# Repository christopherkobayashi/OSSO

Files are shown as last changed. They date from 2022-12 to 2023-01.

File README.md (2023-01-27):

# Osso

Osso is a BeagleBone (White/Black/Green) I/O expansion cape.

The Osso was designed by Franco (nextime) Lanza <franco@nexlab.it>

## Output

The Osso has 8 relays rated at 275VAC@10A.

## Input
Osso has 8 digital inputs.  They can be switched between opto-isolated and non-opto-isolated; the instructions are [here](INPUTS.md)

## Power

The expansion cape is powered by a 12VDC connector (9 to 24VDC supported).  The Osso will supply power to the BeagleBone via the expansion pins.

## Software

A test Debian GNU/Linux install is available.  Installation instructions are [here](TEST.md)

## Miscellaneous

The size of the cape is a standard format for 9 units DIN mount boxes.

## Pictures

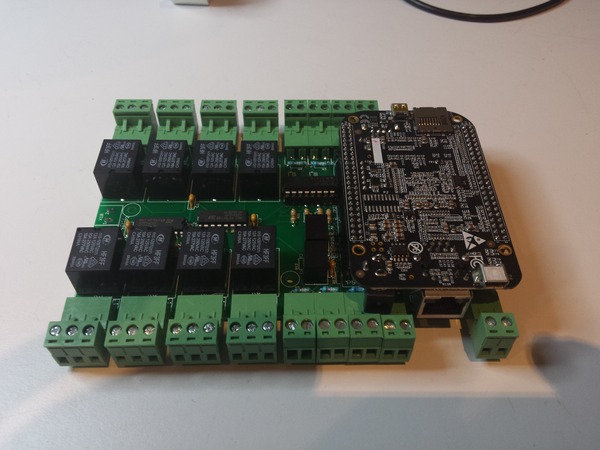
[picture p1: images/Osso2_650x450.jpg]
Osso board

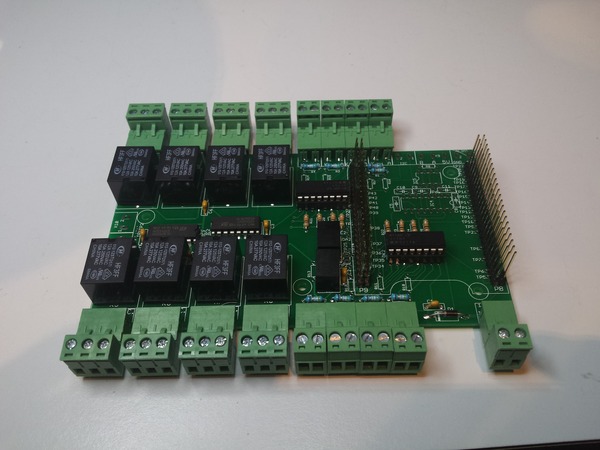
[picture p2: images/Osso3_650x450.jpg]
Osso board


Pin diagram (green dot pins are optional, other required):

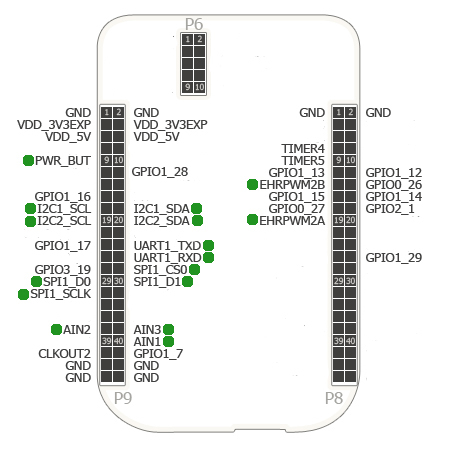
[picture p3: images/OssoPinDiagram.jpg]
Osso Pin Diagram


## Miscellaneous

For more information, please visit https://www.nexlab.net/

Do you like our cape? Donations in Bitcoin is accepted at 1ABepVhyYuZNxiMQe8atPi4tRJZKkpRDqb (CK note: verify this address with nextime before sending any Bitcoin!)

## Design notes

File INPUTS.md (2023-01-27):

# Osso inputs: opto or non-opto insulated digital inputs.

Osso come with the ability to change digital inputs to optoinsulated or non optoinsulated.

Which one you need to use depend on what you really need:

If you want to have a simple "open close" circuit, with a clean contact like a simple push button, and you don't have interference issues or very long ( > 50 meters ) wiring for inputs, non-opto insulated it's the way to go.

If you need to push current to the inputs, opto-insulated is your right choice, so, you can put from 2 to 24V DC voltage on the digital inputs.

Switch from one to another on Osso is easy: you just need to swap some IC, and in the last case to solder 8 resistors.

Inputs on Osso are organized in groups of 4: from 1 to 4 and from 5 to 8. Different groups can be used in different modes.

With Osso we provide also a couple of ICs, so, you don't need any other spare component.

We provide: 

* 2x DIP16 TLP521-4x opto-decoupler 
* 2x 4116-R LF resistors array

By default, if nor otherwise requested, we mount on Osso the array resistors for non-opto isolated inputs.

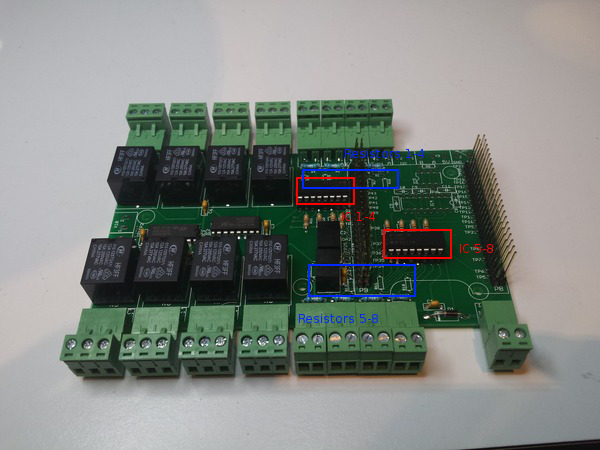
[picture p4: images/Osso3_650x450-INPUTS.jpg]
Osso board


## Opto-insulated configuration
Uses TLP521-4x ICs in the two dip16 sockets as on the image, no resistors are needed. You will need to put 2 to 24 Volts on the input to change input status ( resistors on inputs are for max 250mW! )

## Non-opto insulated configuration
Uses 4116R-LF ICs in the two dip16 sockets as on the image, no resistors are needed. It will change input status on short.

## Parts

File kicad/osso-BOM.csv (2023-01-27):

Source: | /home/wileyc/src/OSSO/kicad/osso.kicad_sch
Date: | Fri 27 Jan 2023 08:09:53 PM JST
Tool: | Eeschema (6.0.11)
Generator: | /usr/share/kicad/plugins/bom_csv_grouped_by_value_with_fp.py
Component Count: | 150
Ref | Qnty | Value | Cmp name | Footprint | Description | Vendor
ALIM0, ALIM1, | 2 | Alim | MORSETTO_2 | osso:W237-102
C1, C2, C3, C4, C5, C6, C7, C8, C9, C10, C11, | 11 | C5/2.5 | C5{slash}2.5 | osso:C5B2.5
D1, | 1 | DIODE | DIODE | osso:DO15-12
H1, H2, H3, H4, H5, | 5 | HOLE3.0 | HOLE3.0 | osso:3,0
I2C0, | 1 | I2C | MORSETTO_2 | osso:W237-102
IC1, IC6, | 2 | REGOLATORE_TENSIONESWITCHING | REGOLATORE_TENSIONESWITCHING | osso:MT6-3
IC2, IC3, | 2 | ULN2003AN | ULN2003AN | osso:DIL16
IC4, | 1 | MAX202CPE | MAX202CPE | osso:DIL16
IC5, | 1 | MAX481CPA | MAX481CPA | osso:DIL08
IN1, | 1 | IN1 | MORSETTO_2 | osso:W237-102
IN2, | 1 | IN2 | MORSETTO_2 | osso:W237-102
IN3, | 1 | IN3 | MORSETTO_2 | osso:W237-102
IN4, | 1 | IN4 | MORSETTO_2 | osso:W237-102
IN5, | 1 | IN5 | MORSETTO_2 | osso:W237-102
IN6, | 1 | IN6 | MORSETTO_2 | osso:W237-102
IN7, | 1 | IN7 | MORSETTO_2 | osso:W237-102
IN8, | 1 | IN8 | MORSETTO_2 | osso:W237-102
J1, | 1 | RTC_MICROROBOT_ALGOZINO-PTH | RTC_MICROROBOT_ALGOZINO-PTH | osso:RTC_MICROBOT_ALGOZINO
JP1, | 1 | JUMPER_2 | JUMPER_2 | osso:JP1
K1, K2, K3, K4, K5, K6, K7, K8, | 8 | RELAY | RELAY | osso:G5LE
OK1, OK2, | 2 | OPTOISOLATORE_ILQ620 | OPTOISOLATORE_ILQ620 | osso:DIL16
PCB1, | 1 | BORDO_UNIXMEDIA150X83,5 | BORDO_UNIXMEDIA150X83,5 | osso:BORD_UNIXMEDIA
R1, R2, R3, R4, R5, R6, R7, R8, | 8 | 49 | RESISTOR0204{slash}7 | osso:0204_7
R9, R13, R15, R23, | 4 | RESISTOR0204/7 | RESISTOR0204{slash}7 | osso:0204_7
R10, R11, R12, R14, R16, R17, R18, R19, R20, R21, R22, R24, R25, | 13 | 10k | RESISTOR0204{slash}7 | osso:0204_7
SCL2, | 1 | TPPAD1-13 | TPPAD1-13 | osso:TEST_POINT
SDA2, | 1 | TP1 | TPPAD1-13 | osso:TEST_POINT
SS1, | 1 | CE-MARK | CE-MARK | osso:CE-MARK-0.2
SS2, | 1 | PB-MARK | PB-MARK | osso:PB-MARK-0.2
TP1, TP2, TP3, TP4, TP5, TP6, TP7, TP8, TP9, TP10, TP11, TP12, TP13, TP14, TP15, TP16, TP17, TP18, TP19, TP20, TP21, TP22, TP23, TP24, TP25, TP26, TP27, TP28, TP29, TP30, TP31, TP32, TP33, TP34, TP35, TP36, TP37, TP38, TP39, TP40, TP41, TP42, TP43, TP44, TP45, TP46, TP47, TP48, TP49, TP50, TP51, TP52, TP53, TP54, TP55, TP56, TP57, TP58, TP59, TP60, TP61, TP62, | 62 | TPPAD1-13 | TPPAD1-13 | osso:TEST_POINT
U$1, | 1 | BEAGLEBONE_OUTLINE | BEAGLEBONE_OUTLINE | osso:BEAGLEBONE_SHIELD
X1, | 1 | X1 | MORSETTO_3 | osso:W237-103
X2, | 1 | X2 | MORSETTO_3 | osso:W237-103
X3, | 1 | X3 | MORSETTO_3 | osso:W237-103
X4, | 1 | X4 | MORSETTO_3 | osso:W237-103
X5, | 1 | X5 | MORSETTO_3 | osso:W237-103
X6, | 1 | X6 | MORSETTO_3 | osso:W237-103
X7, | 1 | X7 | MORSETTO_3 | osso:W237-103
X8, | 1 | X8 | MORSETTO_3 | osso:W237-103
X9, | 1 | MORSETTO_3 | MORSETTO_3 | osso:W237-103
X10, X11, | 2 | MORSETTO_2 | MORSETTO_2 | osso:W237-102

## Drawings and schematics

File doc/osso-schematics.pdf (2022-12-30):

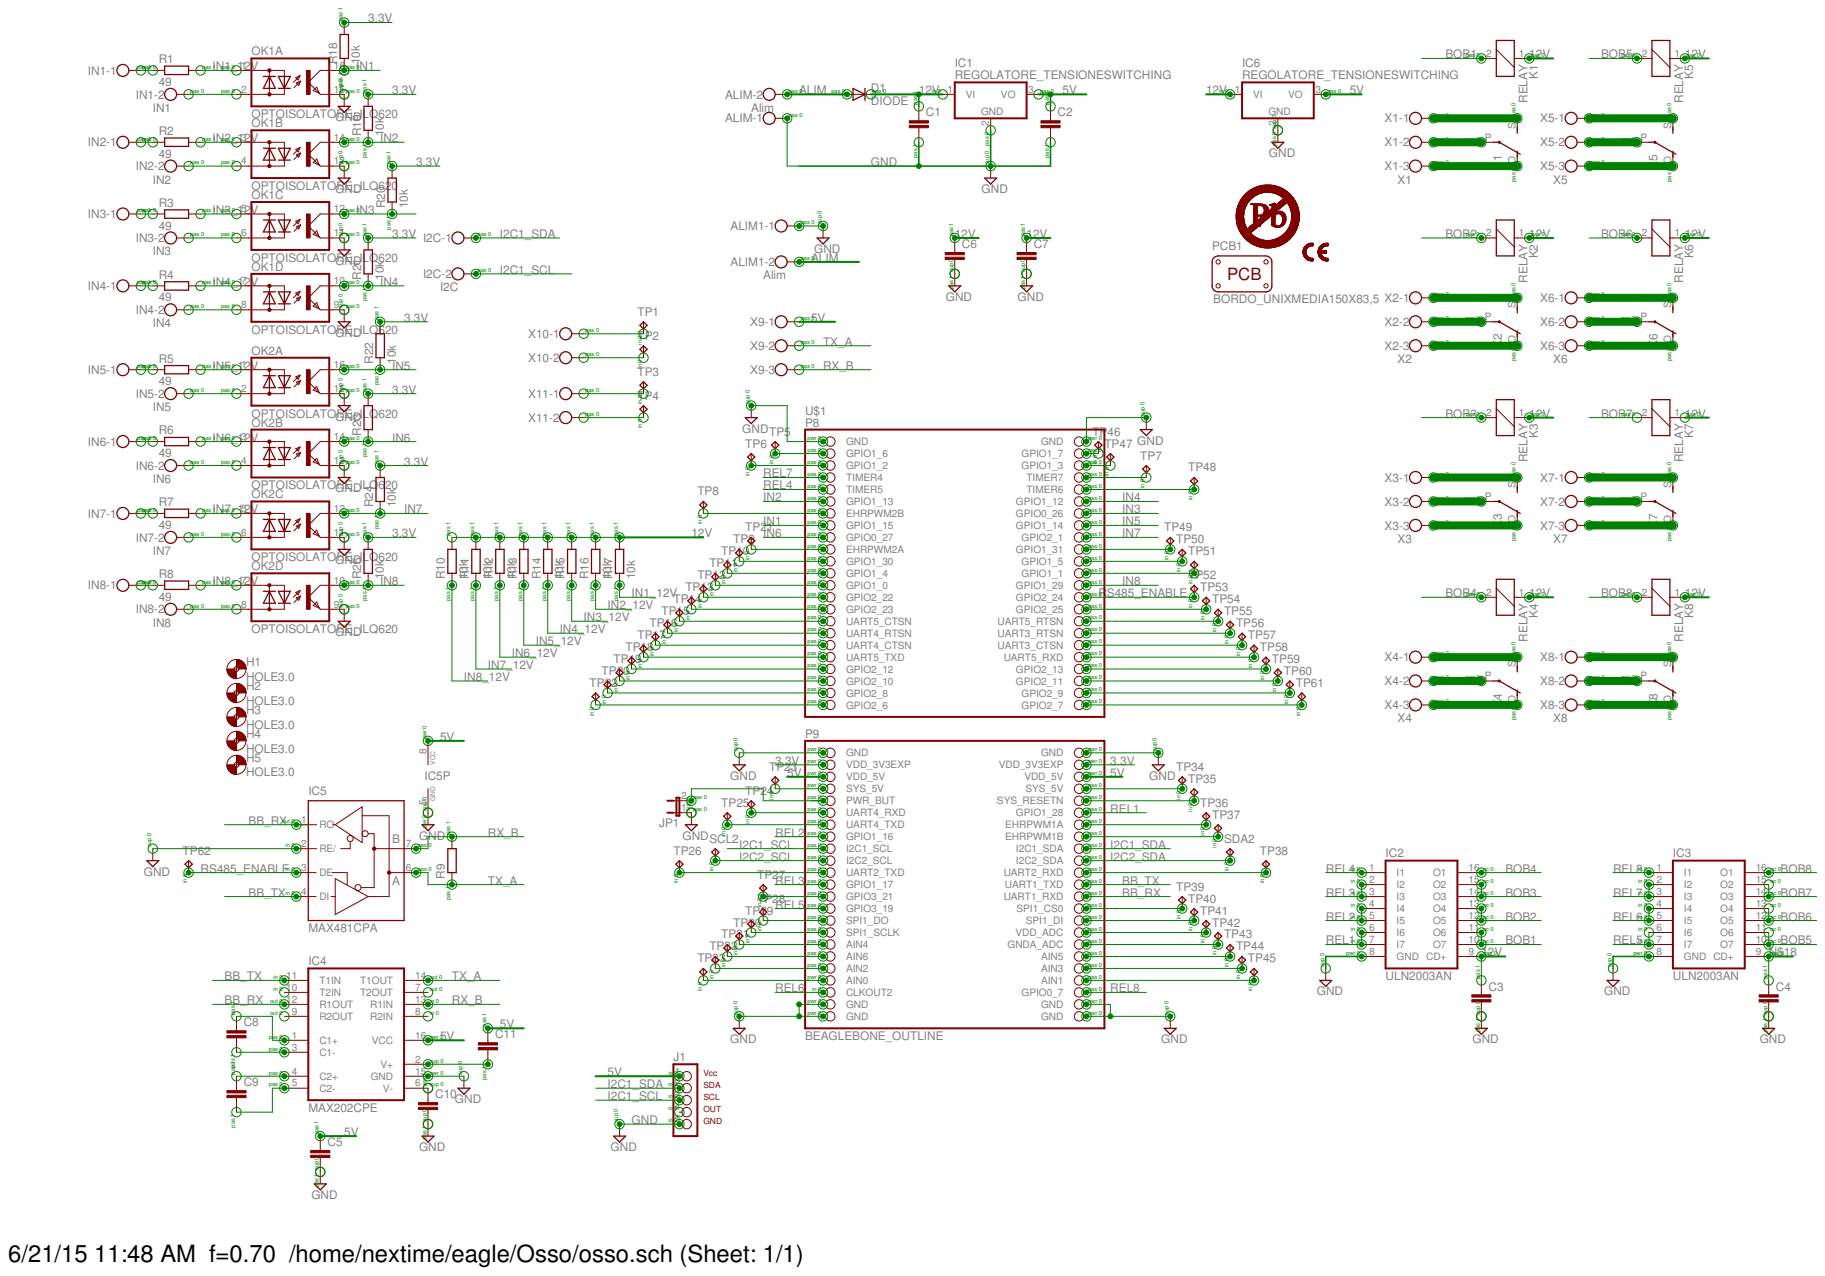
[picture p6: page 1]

RELAY RELAY

sup 0 sup 0 sup 0 sup 0
GND GND GND GND

pas 1 pas 1

6/21/15 11:48 AM f=0.70 /home/nextime/eagle/Osso/osso.sch (Sheet: 1/1)

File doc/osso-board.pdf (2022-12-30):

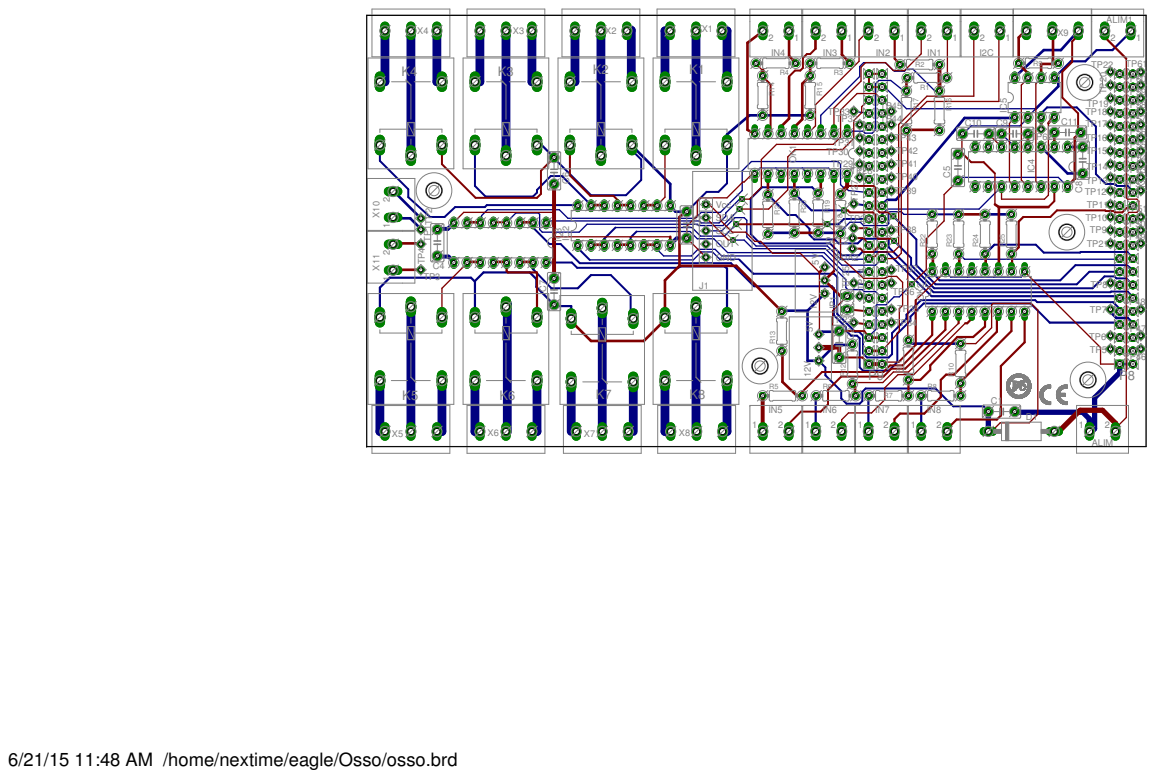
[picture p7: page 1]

ALIM1
TP49 TP50 TP51 TP52 TP53 TP54 TP55 TP56 TP57 TP58 TP59 TP60 TP61

6/21/15 11:48 AM /home/nextime/eagle/Osso/osso.brd

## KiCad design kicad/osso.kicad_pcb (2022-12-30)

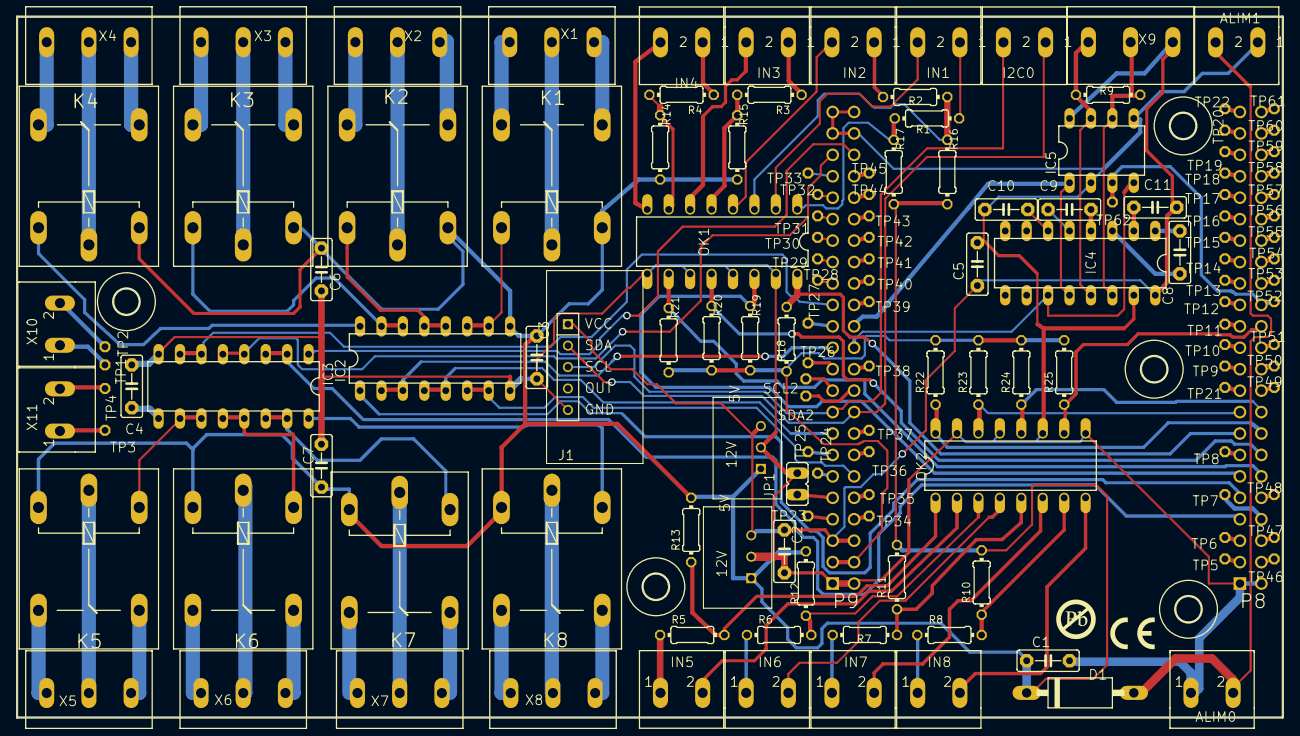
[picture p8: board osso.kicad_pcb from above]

Board: 4 copper layers, 150.0 x 83.0 mm, 150 parts (1 on the bottom side), 154 nets.

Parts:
ALIM0, ALIM1: Alim; W237-102
C1, C2, C3, C4, C5, C6, C7, C8, C9, C10, C11: C5B2.5
D1: DIODE; DO15-12
H1, H2, H3, H4, H5: HOLE3.0; 3,0
I2C0: I2C; W237-102
IC1, IC6: REGOLATORE_TENSIONESWITCHING; MT6-3
IC2, IC3: ULN2003AN; DIL16
IC4: MAX202CPE; DIL16
IC5: MAX481CPA; DIL08
IN1: IN1; W237-102
IN2: IN2; W237-102
IN3: IN3; W237-102
IN4: IN4; W237-102
IN5: IN5; W237-102
IN6: IN6; W237-102
IN7: IN7; W237-102
IN8: IN8; W237-102
J1: RTC_MICROROBOT_ALGOZINO-PTH; RTC_MICROBOT_ALGOZINO
JP1: JP1
K1, K2, K3, K4, K5, K6, K7, K8: RELAY; G5LE
OK1, OK2: OPTOISOLATORE_ILQ620; DIL16
PCB1: BORDO_UNIXMEDIA150X83,5; BORD_UNIXMEDIA
R1, R2, R3, R4, R5, R6, R7, R8: 49; 0204_7
R9, R13, R15, R23: 0204_7
R10, R11, R12, R14, R16, R17, R18, R19, R20, R21, R22, R24, R25: 10k; 0204_7
SCL2: TPPAD1-13; TEST_POINT
SDA2: TP1; TEST_POINT
SS1: CE-MARK; CE-MARK-0.2
SS2: PB-MARK; PB-MARK-0.2
TP1, TP2, TP3, TP4, TP5, TP6, TP7, TP8, TP9, TP10, TP11, TP12, TP13, TP14, TP15, TP16, TP17, TP18, TP19, TP20, TP21, TP22, TP23, TP24, TP25, TP26, TP27, TP28, TP29, TP30, TP31, TP32, TP33, TP34, TP35, TP36, TP37, TP38, TP39, TP40, TP41, TP42, TP43, TP44, TP45, TP46, TP47, TP48, TP49, TP50, TP51, TP52, TP53, TP54, TP55, TP56, TP57, TP58, TP59, TP60, TP61, TP62: TPPAD1-13; TEST_POINT
U$1: BEAGLEBONE_OUTLINE; BEAGLEBONE_SHIELD
X1: X1; W237-103
X2: X2; W237-103
X3: X3; W237-103
X4: X4; W237-103
X5: X5; W237-103
X6: X6; W237-103
X7: X7; W237-103
X8: X8; W237-103
X9: W237-103
X10, X11: W237-102

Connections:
3.3V: R18.2, R19.2, R20.2, R21.2, R22.2, R23.2, R24.2, R25.2, U$1.49, U$1.50
5V: C2.1, C5.1, C11.1, IC1.3, IC4.16, IC5.8, IC6.3, J1.1, U$1.51, U$1.52, X9.1
12V: C1.1, C3.1, C6.1, C7.1, D1.C, IC1.1, IC2.9, IC6.1, K1.1, K2.1, K3.1, K4.1, K5.1, K6.1, K7.1, K8.1, R10.2, R11.2, R12.2, R13.2, R14.2, R15.2, R16.2, R17.2
ALIM: ALIM0.2, ALIM1.2, D1.A
BB_RX: IC4.12, IC5.1, U$1.72
BB_TX: IC4.11, IC5.4, U$1.70
BOB1: IC2.10, IC2.11, K1.2
BOB2: IC2.12, IC2.13, K2.2
BOB3: IC2.14, IC2.15, K3.2
BOB4: IC2.16, K4.2
BOB5: IC3.10, IC3.11, K5.2
BOB6: IC3.12, IC3.13, K6.2
BOB7: IC3.14, IC3.15, K7.2
BOB8: IC3.16, K8.2
GND: ALIM0.1, ALIM1.1, C1.2, C2.2, C3.2, C4.2, C5.2, C6.2, C7.2, C10.2, IC1.2, IC2.8, IC3.8, IC4.15, IC5.2, IC5.5, IC6.2, J1.5, JP1.1, OK1.9, OK1.11, OK1.13, OK1.15, OK2.9, OK2.11, OK2.13, OK2.15, U$1.1, U$1.2, U$1.47, U$1.48, U$1.89, U$1.90, U$1.91, U$1.92
I2C1_SCL: I2C0.2, J1.3, U$1.63
I2C1_SDA: I2C0.1, J1.2, U$1.64
I2C2_SCL: SCL2.TP, U$1.65
I2C2_SDA: SDA2.TP, U$1.66
IN1: OK1.16, R18.1, U$1.15
IN1_12V: OK1.1, R1.2, R17.1
IN2: OK1.14, R19.1, U$1.11
IN2_12V: OK1.3, R2.2, R16.1
IN3: OK1.12, R20.1, U$1.14
IN3_12V: OK1.5, R3.2, R15.1
IN4: OK1.10, R21.1, U$1.12
IN4_12V: OK1.7, R4.2, R14.1
IN5: OK2.16, R22.1, U$1.16
IN5_12V: OK2.1, R5.2, R13.1
IN6: OK2.14, R23.1, U$1.17
IN6_12V: OK2.3, R6.2, R12.1
IN7: OK2.12, R24.1, U$1.18
IN7_12V: OK2.5, R7.2, R11.1
IN8: OK2.10, R25.1, U$1.26
IN8_12V: OK2.7, R8.2, R10.1
unnamed: IN1.1, R1.1
unnamed: TP1.TP, X10.1
unnamed: K5.S, X5.1
unnamed: K5.P, X5.2
unnamed: K5.O, X5.3
unnamed: K6.S, X6.1
unnamed: K6.P, X6.2
unnamed: K6.O, X6.3
unnamed: K3.S, X3.1
unnamed: K3.P, X3.2
unnamed: K3.O, X3.3
unnamed: C4.1, IC3.9
unnamed: K7.S, X7.1
unnamed: K7.P, X7.2
unnamed: K4.S, X4.1
unnamed: K4.P, X4.2
unnamed: K4.O, X4.3
unnamed: K8.S, X8.1
unnamed: K8.P, X8.2
unnamed: K8.O, X8.3
unnamed: IN2.1, R2.1
unnamed: TP2.TP, X10.2
unnamed: IN3.1, R3.1
unnamed: TP3.TP, X11.1
unnamed: IN4.1, R4.1
unnamed: TP4.TP, X11.2
unnamed: IN5.1, R5.1
unnamed: TP7.TP, U$1.8
unnamed: IN6.1, R6.1
unnamed: TP22.TP, U$1.45
unnamed: IN7.1, R7.1
unnamed: TP20.TP, U$1.43
unnamed: IN8.1, R8.1
unnamed: TP19.TP, U$1.41
unnamed: IN8.2, OK2.8
unnamed: IN7.2, OK2.6
unnamed: IN6.2, OK2.4
unnamed: IN5.2, OK2.2
unnamed: IN1.2, OK1.2
unnamed: IN2.2, OK1.4
unnamed: IN3.2, OK1.6
unnamed: IN4.2, OK1.8
unnamed: JP1.2, U$1.55
unnamed: TP18.TP, U$1.39
unnamed: TP17.TP, U$1.37
unnamed: TP16.TP, U$1.35
unnamed: TP15.TP, U$1.33
unnamed: TP14.TP, U$1.31
unnamed: TP13.TP, U$1.29
unnamed: TP12.TP, U$1.27
unnamed: TP11.TP, U$1.25
unnamed: TP10.TP, U$1.23
unnamed: TP9.TP, U$1.21
unnamed: TP21.TP, U$1.19
unnamed: TP5.TP, U$1.3
unnamed: TP6.TP, U$1.5
unnamed: K7.O, X7.3
unnamed: TP8.TP, U$1.13
unnamed: TP33.TP, U$1.85
unnamed: TP32.TP, U$1.83
unnamed: TP31.TP, U$1.81
unnamed: TP30.TP, U$1.79
unnamed: TP29.TP, U$1.77
unnamed: TP28.TP, U$1.75
unnamed: TP27.TP, U$1.71
unnamed: TP26.TP, U$1.67
unnamed: TP25.TP, U$1.59
unnamed: TP24.TP, U$1.57
unnamed: TP23.TP, U$1.53
unnamed: TP34.TP, U$1.54
unnamed: TP35.TP, U$1.56
unnamed: TP36.TP, U$1.60
unnamed: TP37.TP, U$1.62
unnamed: TP38.TP, U$1.68
unnamed: TP39.TP, U$1.74
unnamed: TP40.TP, U$1.76
unnamed: TP41.TP, U$1.78
unnamed: TP42.TP, U$1.80
unnamed: TP43.TP, U$1.82
unnamed: TP44.TP, U$1.84
unnamed: TP45.TP, U$1.86
unnamed: TP61.TP, U$1.46
unnamed: TP60.TP, U$1.44
unnamed: TP59.TP, U$1.42
unnamed: TP58.TP, U$1.40
unnamed: TP57.TP, U$1.38
unnamed: TP56.TP, U$1.36
unnamed: TP55.TP, U$1.34
unnamed: TP54.TP, U$1.32
unnamed: TP53.TP, U$1.30
unnamed: TP51.TP, U$1.24
unnamed: TP50.TP, U$1.22
unnamed: TP49.TP, U$1.20
unnamed: TP48.TP, U$1.10
unnamed: TP47.TP, U$1.6
unnamed: TP46.TP, U$1.4
unnamed: C8.1, IC4.1
unnamed: C8.2, IC4.3
unnamed: C9.1, IC4.4
unnamed: C9.2, IC4.5
R1_C: K1.P, X1.2
R1_NA: K1.S, X1.1
R1_NC: K1.O, X1.3
R2_C: K2.P, X2.2
R2_NA: K2.S, X2.1
R2_NC: K2.O, X2.3
REL1: IC2.6, IC2.7, U$1.58
REL2: IC2.4, IC2.5, U$1.61
REL3: IC2.2, IC2.3, U$1.69
REL4: IC2.1, U$1.9
REL5: IC3.6, IC3.7, U$1.73
REL6: IC3.4, IC3.5, U$1.87
REL7: IC3.2, IC3.3, U$1.7
REL8: IC3.1, U$1.88
RS485_ENABLE: IC5.3, TP52.TP, TP62.TP, U$1.28
RX_B: IC4.13, IC5.7, R9.2, X9.3
TX_A: IC4.14, IC5.6, R9.1, X9.2
V+: C11.2, IC4.2
V-: C10.1, IC4.6

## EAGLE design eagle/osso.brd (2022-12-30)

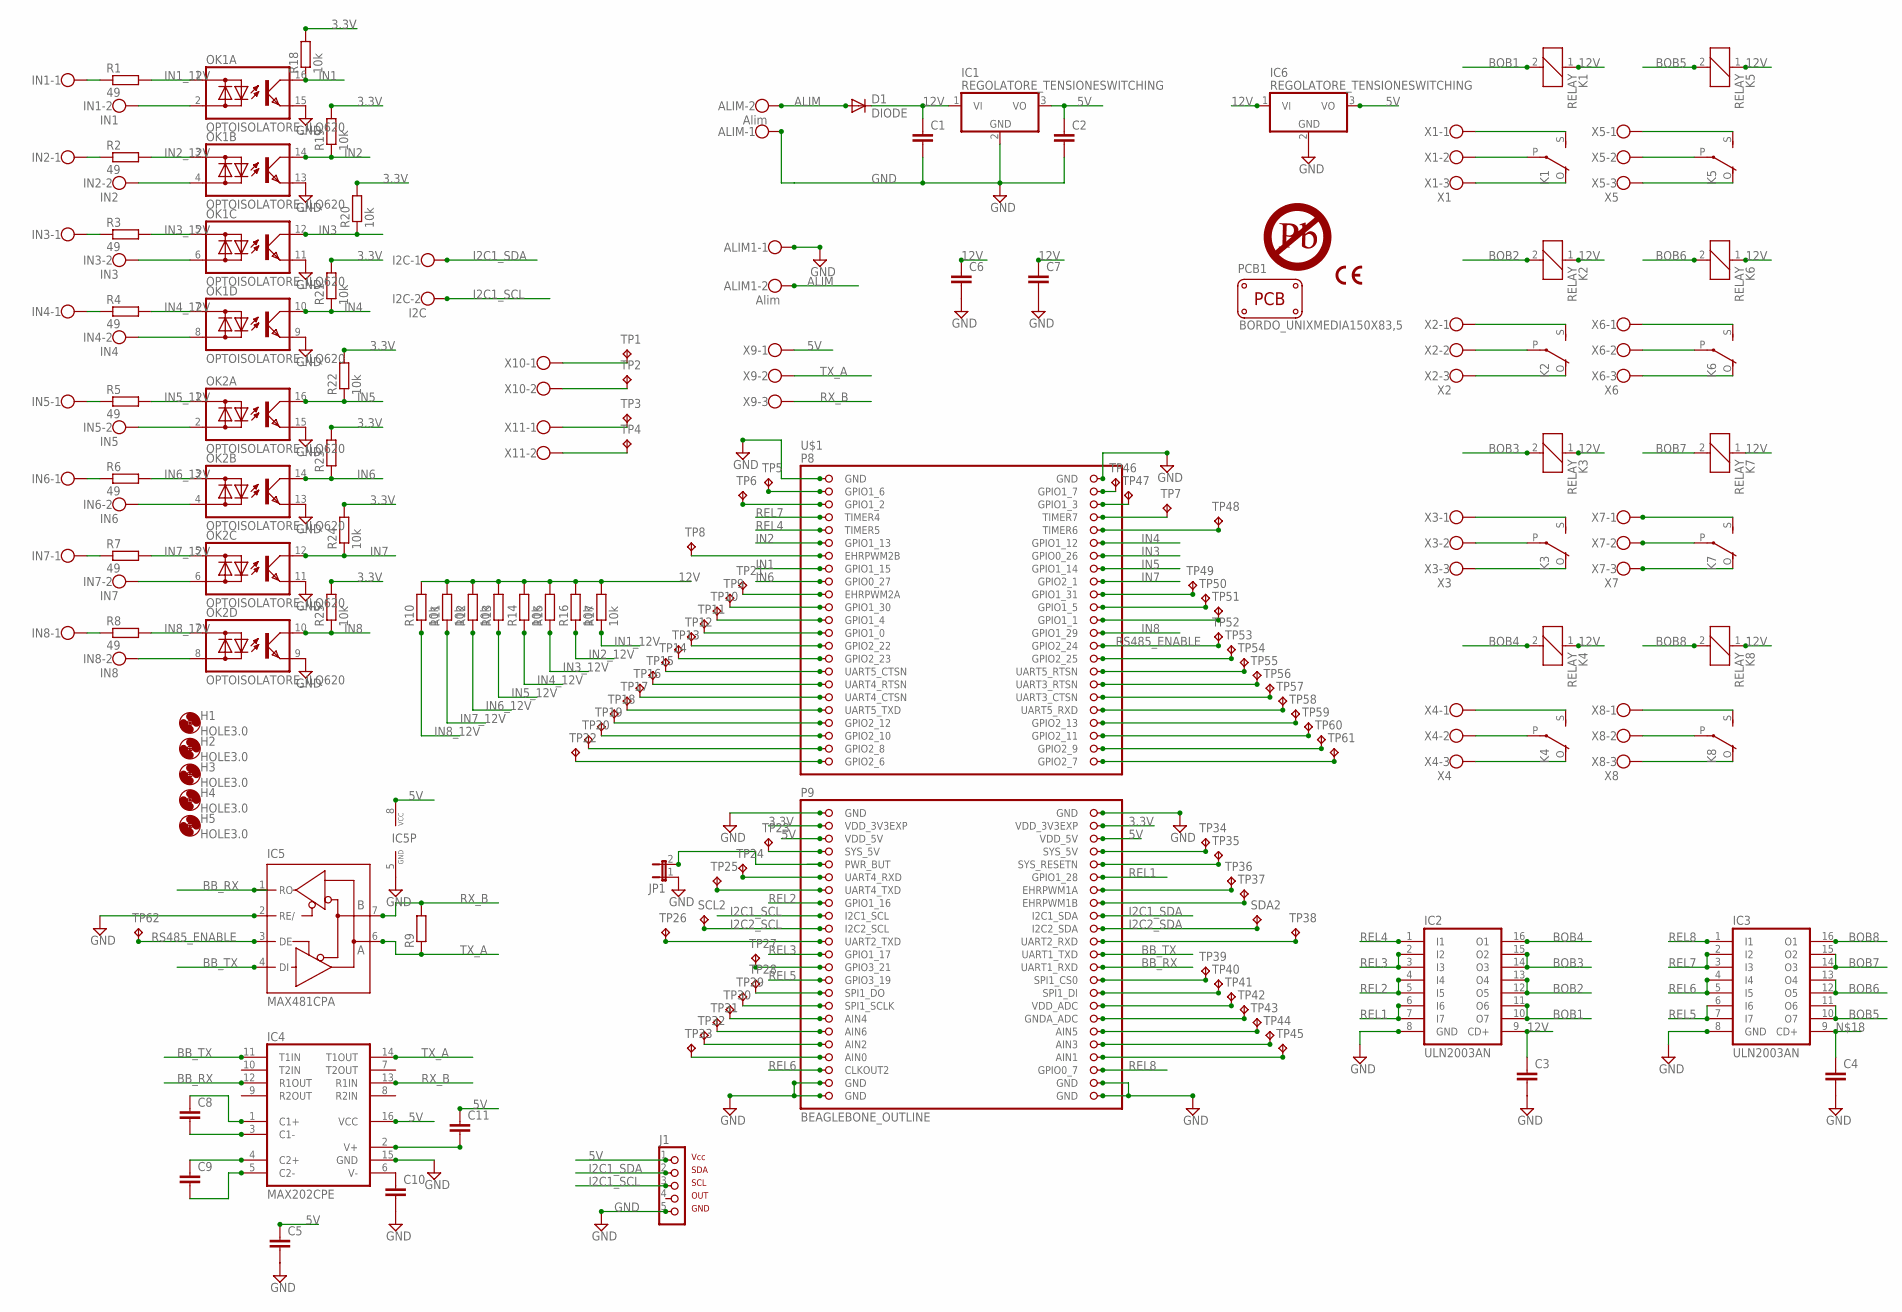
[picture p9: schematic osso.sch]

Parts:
ALIM: Alim; W237-102
ALIM1: Alim; W237-102; MPN 237-102
C1, C2, C3, C4, C5, C6, C7, C8, C9, C10, C11: C5/2.5; C5B2.5
D1: DIODE; DO15-12
H1, H2, H3, H4, H5: HOLE3.0; 3,0
I2C: I2C; W237-102; MPN 237-102
IC1, IC6: REGOLATORE_TENSIONESWITCHING; MT6-3
IC2, IC3: ULN2003AN; DIL16
IC4: MAX202CPE; DIL16
IC5: MAX481CPA; DIL08
IN1: IN1; W237-102
IN2: IN2; W237-102
IN3: IN3; W237-102
IN4: IN4; W237-102
IN5: IN5; W237-102
IN6: IN6; W237-102
IN7: IN7; W237-102
IN8: IN8; W237-102
J1: RTC_MICROROBOT_ALGOZINO-PTH; RTC_MICROBOT_ALGOZINO
JP1: JUMPER_2; JP1
K1, K2, K3, K4, K5, K6, K7, K8: RELAY; G5LE
OK1, OK2: OPTOISOLATORE_ILQ620; DIL16
PCB1: BORDO_UNIXMEDIA150X83,5; BORD_UNIXMEDIA
R1, R2, R3, R4, R5, R6, R7, R8: 49; 0204/7
R9, R13, R15, R23: RESISTOR0204/7; 0204/7
R10, R11, R12, R14, R16, R17, R18, R19, R20, R21, R22, R24, R25: 10k; 0204/7
SCL2: TPPAD1-13; TEST_POINT
SDA2: TP1; TEST_POINT
SS1: CE-MARK; CE-MARK-0.2
SS2: PB-MARK; PB-MARK-0.2
TP1, TP2, TP3, TP4, TP5, TP6, TP7, TP8, TP9, TP10, TP11, TP12, TP13, TP14, TP15, TP16, TP17, TP18, TP19, TP20, TP21, TP22, TP23, TP24, TP25, TP26, TP27, TP28, TP29, TP30, TP31, TP32, TP33, TP34, TP35, TP36, TP37, TP38, TP39, TP40, TP41, TP42, TP43, TP44, TP45, TP46, TP47, TP48, TP49, TP50, TP51, TP52, TP53, TP54, TP55, TP56, TP57, TP58, TP59, TP60, TP61, TP62: TPPAD1-13; TEST_POINT
U$1: BEAGLEBONE_OUTLINE; BEAGLEBONE_SHIELD
X1: X1; W237-103
X2: X2; W237-103
X3: X3; W237-103
X4: X4; W237-103
X5: X5; W237-103
X6: X6; W237-103
X7: X7; W237-103
X8: X8; W237-103
X9: MORSETTO_3; W237-103
X10, X11: MORSETTO_2; W237-102

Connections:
3.3V: R18.2, R19.2, R20.2, R21.2, R22.2, R23.2, R24.2, R25.2, U$1.49 (VDD_3V3EXP), U$1.50 (VDD_3V3EXP)
5V: C2.1, C5.1, C11.1, IC1.3 (VO), IC4.16 (VCC), IC5.8 (VCC), IC6.3 (VO), J1.1, U$1.51 (VDD_5V), U$1.52 (VDD_5V), X9.1
12V: C1.1, C3.1, C6.1, C7.1, D1.C, IC1.1 (VI), IC2.9 (CD+), IC6.1 (VI), K1.1, K2.1, K3.1, K4.1, K5.1, K6.1, K7.1, K8.1, R10.2, R11.2, R12.2, R13.2, R14.2, R15.2, R16.2, R17.2
ALIM: ALIM.2, ALIM1.2, D1.A
BB_RX: IC4.12 (R1OUT), IC5.1 (RO), U$1.72 (UART1_RXD)
BB_TX: IC4.11 (T1IN), IC5.4 (DI), U$1.70 (UART1_TXD)
BOB1: IC2.10 (O7), IC2.11 (O6), K1.2
BOB2: IC2.12 (O5), IC2.13 (O4), K2.2
BOB3: IC2.14 (O3), IC2.15 (O2), K3.2
BOB4: IC2.16 (O1), K4.2
BOB5: IC3.10 (O7), IC3.11 (O6), K5.2
BOB6: IC3.12 (O5), IC3.13 (O4), K6.2
BOB7: IC3.14 (O3), IC3.15 (O2), K7.2
BOB8: IC3.16 (O1), K8.2
GND: ALIM.1, ALIM1.1, C1.2, C2.2, C3.2, C4.2, C5.2, C6.2, C7.2, C10.2, IC1.2 (GND), IC2.8 (GND), IC3.8 (GND), IC4.15 (GND), IC5.2 (RE/), IC5.5 (GND), IC6.2 (GND), J1.5, JP1.1, OK1.9 (E), OK1.11 (E), OK1.13 (E), OK1.15 (E), OK2.9 (E), OK2.11 (E), OK2.13 (E), OK2.15 (E), U$1.1 (GND), U$1.2 (GND), U$1.47 (GND), U$1.48 (GND), U$1.89 (GND), U$1.90 (GND), U$1.91 (GND), U$1.92 (GND)
I2C1_SCL: I2C.2, J1.3, U$1.63 (I2C1_SCL)
I2C1_SDA: I2C.1, J1.2, U$1.64 (I2C1_SDA)
I2C2_SCL: SCL2.TP, U$1.65 (I2C2_SCL)
I2C2_SDA: SDA2.TP, U$1.66 (I2C2_SDA)
IN1: OK1.16 (C), R18.1, U$1.15 (GPIO1_15)
IN1_12V: OK1.1 (AC1), R1.2, R17.1
IN2: OK1.14 (C), R19.1, U$1.11 (GPIO1_13)
IN2_12V: OK1.3 (AC1), R2.2, R16.1
IN3: OK1.12 (C), R20.1, U$1.14 (GPIO0_26)
IN3_12V: OK1.5 (AC1), R3.2, R15.1
IN4: OK1.10 (C), R21.1, U$1.12 (GPIO1_12)
IN4_12V: OK1.7 (AC1), R4.2, R14.1
IN5: OK2.16 (C), R22.1, U$1.16 (GPIO1_14)
IN5_12V: OK2.1 (AC1), R5.2, R13.1
IN6: OK2.14 (C), R23.1, U$1.17 (GPIO0_27)
IN6_12V: OK2.3 (AC1), R6.2, R12.1
IN7: OK2.12 (C), R24.1, U$1.18 (GPIO2_1)
IN7_12V: OK2.5 (AC1), R7.2, R11.1
IN8: OK2.10 (C), R25.1, U$1.26 (GPIO1_29)
IN8_12V: OK2.7 (AC1), R8.2, R10.1
unnamed: IN1.1, R1.1
unnamed: TP1.TP, X10.1
unnamed: K5.S, X5.1
unnamed: K5.P, X5.2
unnamed: K5.O, X5.3
unnamed: K6.S, X6.1
unnamed: K6.P, X6.2
unnamed: K6.O, X6.3
unnamed: K3.S, X3.1
unnamed: K3.P, X3.2
unnamed: K3.O, X3.3
unnamed: C4.1, IC3.9 (CD+)
unnamed: K7.S, X7.1
unnamed: K7.P, X7.2
unnamed: K4.S, X4.1
unnamed: K4.P, X4.2
unnamed: K4.O, X4.3
unnamed: K8.S, X8.1
unnamed: K8.P, X8.2
unnamed: K8.O, X8.3
unnamed: IN2.1, R2.1
unnamed: TP2.TP, X10.2
unnamed: IN3.1, R3.1
unnamed: TP3.TP, X11.1
unnamed: IN4.1, R4.1
unnamed: TP4.TP, X11.2
unnamed: IN5.1, R5.1
unnamed: TP7.TP, U$1.8 (TIMER7)
unnamed: IN6.1, R6.1
unnamed: TP22.TP, U$1.45 (GPIO2_6)
unnamed: IN7.1, R7.1
unnamed: TP20.TP, U$1.43 (GPIO2_8)
unnamed: IN8.1, R8.1
unnamed: TP19.TP, U$1.41 (GPIO2_10)
unnamed: IN8.2, OK2.8 (AC2)
unnamed: IN7.2, OK2.6 (AC2)
unnamed: IN6.2, OK2.4 (AC2)
unnamed: IN5.2, OK2.2 (AC2)
unnamed: IN1.2, OK1.2 (AC2)
unnamed: IN2.2, OK1.4 (AC2)
unnamed: IN3.2, OK1.6 (AC2)
unnamed: IN4.2, OK1.8 (AC2)
unnamed: JP1.2, U$1.55 (PWR_BUT)
unnamed: TP18.TP, U$1.39 (GPIO2_12)
unnamed: TP17.TP, U$1.37 (UART5_TXD)
unnamed: TP16.TP, U$1.35 (UART4_CTSN)
unnamed: TP15.TP, U$1.33 (UART4_RTSN)
unnamed: TP14.TP, U$1.31 (UART5_CTSN)
unnamed: TP13.TP, U$1.29 (GPIO2_23)
unnamed: TP12.TP, U$1.27 (GPIO2_22)
unnamed: TP11.TP, U$1.25 (GPIO1_0)
unnamed: TP10.TP, U$1.23 (GPIO1_4)
unnamed: TP9.TP, U$1.21 (GPIO1_30)
unnamed: TP21.TP, U$1.19 (EHRPWM2A)
unnamed: TP5.TP, U$1.3 (GPIO1_6)
unnamed: TP6.TP, U$1.5 (GPIO1_2)
unnamed: K7.O, X7.3
unnamed: TP8.TP, U$1.13 (EHRPWM2B)
unnamed: TP33.TP, U$1.85 (AIN0)
unnamed: TP32.TP, U$1.83 (AIN2)
unnamed: TP31.TP, U$1.81 (AIN6)
unnamed: TP30.TP, U$1.79 (AIN4)
unnamed: TP29.TP, U$1.77 (SPI1_SCLK)
unnamed: TP28.TP, U$1.75 (SPI1_DO)
unnamed: TP27.TP, U$1.71 (GPIO3_21)
unnamed: TP26.TP, U$1.67 (UART2_TXD)
unnamed: TP25.TP, U$1.59 (UART4_TXD)
unnamed: TP24.TP, U$1.57 (UART4_RXD)
unnamed: TP23.TP, U$1.53 (SYS_5V)
unnamed: TP34.TP, U$1.54 (SYS_5V)
unnamed: TP35.TP, U$1.56 (SYS_RESETN)
unnamed: TP36.TP, U$1.60 (EHRPWM1A)
unnamed: TP37.TP, U$1.62 (EHRPWM1B)
unnamed: TP38.TP, U$1.68 (UART2_RXD)
unnamed: TP39.TP, U$1.74 (SPI1_CS0)
unnamed: TP40.TP, U$1.76 (SPI1_DI)
unnamed: TP41.TP, U$1.78 (VDD_ADC)
unnamed: TP42.TP, U$1.80 (GNDA_ADC)
unnamed: TP43.TP, U$1.82 (AIN5)
unnamed: TP44.TP, U$1.84 (AIN3)
unnamed: TP45.TP, U$1.86 (AIN1)
unnamed: TP61.TP, U$1.46 (GPIO2_7)
unnamed: TP60.TP, U$1.44 (GPIO2_9)
unnamed: TP59.TP, U$1.42 (GPIO2_11)
unnamed: TP58.TP, U$1.40 (GPIO2_13)
unnamed: TP57.TP, U$1.38 (UART5_RXD)
unnamed: TP56.TP, U$1.36 (UART3_CTSN)
unnamed: TP55.TP, U$1.34 (UART3_RTSN)
unnamed: TP54.TP, U$1.32 (UART5_RTSN)
unnamed: TP53.TP, U$1.30 (GPIO2_25)
unnamed: TP51.TP, U$1.24 (GPIO1_1)
unnamed: TP50.TP, U$1.22 (GPIO1_5)
unnamed: TP49.TP, U$1.20 (GPIO1_31)
unnamed: TP48.TP, U$1.10 (TIMER6)
unnamed: TP47.TP, U$1.6 (GPIO1_3)
unnamed: TP46.TP, U$1.4 (GPIO1_7)
unnamed: C8.1, IC4.1 (C1+)
unnamed: C8.2, IC4.3 (C1-)
unnamed: C9.1, IC4.4 (C2+)
unnamed: C9.2, IC4.5 (C2-)
R1_C: K1.P, X1.2
R1_NA: K1.S, X1.1
R1_NC: K1.O, X1.3
R2_C: K2.P, X2.2
R2_NA: K2.S, X2.1
R2_NC: K2.O, X2.3
REL1: IC2.6 (I6), IC2.7 (I7), U$1.58 (GPIO1_28)
REL2: IC2.4 (I4), IC2.5 (I5), U$1.61 (GPIO1_16)
REL3: IC2.2 (I2), IC2.3 (I3), U$1.69 (GPIO1_17)
REL4: IC2.1 (I1), U$1.9 (TIMER5)
REL5: IC3.6 (I6), IC3.7 (I7), U$1.73 (GPIO3_19)
REL6: IC3.4 (I4), IC3.5 (I5), U$1.87 (CLKOUT2)
REL7: IC3.2 (I2), IC3.3 (I3), U$1.7 (TIMER4)
REL8: IC3.1 (I1), U$1.88 (GPIO0_7)
RS485_ENABLE: IC5.3 (DE), TP52.TP, TP62.TP, U$1.28 (GPIO2_24)
RX_B: IC4.13 (R1IN), IC5.7 (B), R9.2, X9.3
TX_A: IC4.14 (T1OUT), IC5.6 (A), R9.1, X9.2
V+: C11.2, IC4.2 (V+)
V-: C10.1, IC4.6 (V-)

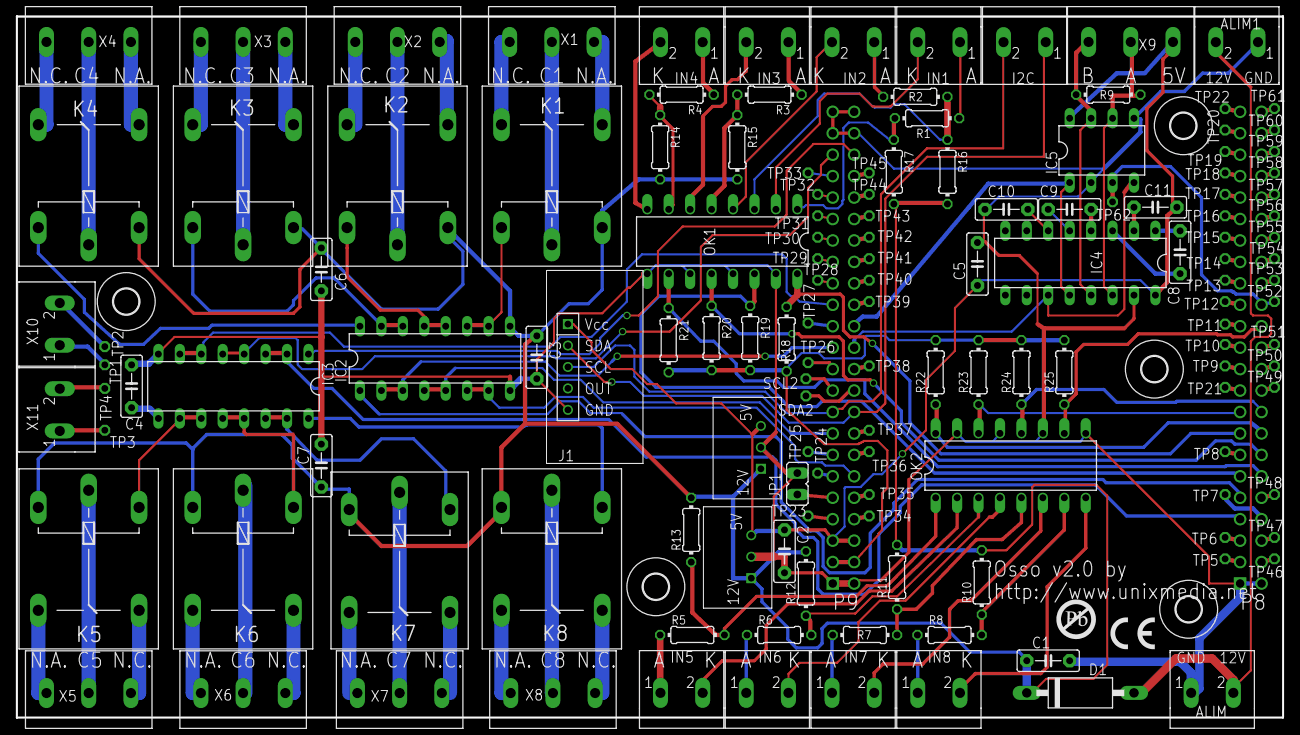
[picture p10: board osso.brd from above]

Board: 4 copper layers, 150.0 x 83.0 mm, 150 parts (1 on the bottom side), 154 nets.

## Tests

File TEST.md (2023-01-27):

Osso cape for BeagleBone black preinstalled Debian GNU/Linux for tests.

WARNING: this will install a debian system in the internal eMMC, backup any data before to proceeding!!!

Copy the disk image on a microSD card of 4 or more gigabytes with:

* wget https://web.archive.org/web/20230127104226/http://www.nexlab.net/Ossotest.img.xz
* xzcat Ossotest.img.xz | dd of=/dev/sdX

where /dev/sdX is the device of your microSD card.

Insert the microSD in the beaglebone black slot and start the board pressing the microswitch closest to the microSD.

Take a coffee break, it will need some times to flash your eMMC. When done, the 4 blue user leds will fixed light on.

Switch off the BeagleBone, remove the microSD, start the BeagleBone again.

The Osso test install get an IP address by DHCP and have a second static IP at 192.168.181.1, the root password is osso

Enjoy!

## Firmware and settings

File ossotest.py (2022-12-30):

#!/usr/bin/env python
"""
OSSO test script.
To run this you need to install devicetree support for
Osso board from https://github.com/unixmedia/Osso
and Adafruit I/O library for beaglebone
from https://github.com/adafruit/adafruit-beaglebone-io-python
(and, of course, python!)
"""
import sys, time
import Adafruit_BBIO.GPIO as GPIO

INPUTS={
         1:'P8_15',
         2:'P8_11',
         3:'P8_14',
         4:'P8_12',
         5:'P8_16',
         6:'P8_17',
         7:'P8_17',
         8:'P8_26'
      }

RELAYS={
         1:'P9_12',
         2:'P9_15',
         3:'P9_23',
         4:'P8_9',
         5:'P9_27',
         6:'P9_41',
         7:'P8_7',
         8:'P9_42'
      }

def printhelp():
   print "Usage:", sys.argv[0], "<input|relay>"
   print
   print "Example:"
   print
   print sys.argv[0], "input 3"
   print
   print sys.argv[0], "relay 2"
   print
def initialize():
   for i in INPUTS.values():
      GPIO.setup(i, GPIO.IN)
   for i in RELAYS.values():
      GPIO.setup(i, GPIO.OUT)

def relay(rel):
   GPIO.output(RELAYS[rel], GPIO.HIGH)
   print 'RELAY', rel, 'IS NOW ON (ctrl+C to exit, on exit any relay will be switched off)'
   while 1: time.sleep(1)

def digitalinp(inp):
   print 'INPUT', inp, 'IS', 'open' if GPIO.input(INPUTS[inp]) else 'close'
   print
   print 'Waiting for a state change... (or ctrl+C to exit)'
   GPIO.wait_for_edge(INPUTS[inp], GPIO.BOTH)
   time.sleep(.01) # Adafruit library needs a little time to detect right status
   print 'INPUT', inp, 'IS NOW', 'open' if GPIO.input(INPUTS[inp]) else 'close'

def custom_excepthook(type, value, traceback):
   if type is KeyboardInterrupt:
      print 'Exit.'
      return # do nothing
   else:
      sys.__excepthook__(type, value, traceback)

sys.excepthook=custom_excepthook

if __name__=='__main__':
   try:
      if (len(sys.argv)>=3
         and sys.argv[1]=='relay'
         and int(sys.argv[2]) in range(1, 9)):
         initialize()
         relay(int(sys.argv[2]))
         sys.exit(0)
      elif (len(sys.argv)>=3
         and sys.argv[1]=='input'
         and int(sys.argv[2]) in range(1, 9)):
         initialize()
         digitalinp(int(sys.argv[2]))
         sys.exit(0)
   except KeyboardInterrupt:
      sys.exit(0)
   printhelp()
   sys.exit(1)

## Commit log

2022-12-30 Initial import.
    [osso.brd, osso.sch]
2022-12-30 Add KiCAD conversion.
    [osso.brd, osso.kicad_pcb, osso.kicad_sch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]
2022-12-30 Move Eagle files to subdirectory.
    [osso.brd, osso.sch]
2022-12-30 Add gerbers.
    [osso-B_Courtyard.gbr, osso-B_Cu.gbl, osso-B_Fab.gbr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]
2023-01-27 Add BOM and footprints.
    [osso-BOM.csv]
